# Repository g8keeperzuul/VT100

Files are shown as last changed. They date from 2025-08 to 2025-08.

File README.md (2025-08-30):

# VT100 Serial Terminal

This VT100 serial terminal recreation is approximately 2/3rds [actual size](https://vt100.net/docs/vt100-ug/chapter2.html).
The 3D model was created from scratch in an attempt to be faithful to the style of the original. I also wanted to take advantage of a larger print bed size. It requires a large format print bed (model width is 30cm) to print as is, but can be cut to accommodate smaller print beds. 
The internals accommodate a Raspberry Pi, a small power distribution outlet and a serial port adapter. 

This project was absolutely inspired by the good work of [Michael Gardi](https://hackaday.io/project/177596-23-scale-vt100-terminal-reproduction) and [Lars Brinkhoff](https://github.com/larsbrinkhoff/terminal-simulator). I used the same display hardware, but different serial interface and an upgraded Pi. 

# Enclosure

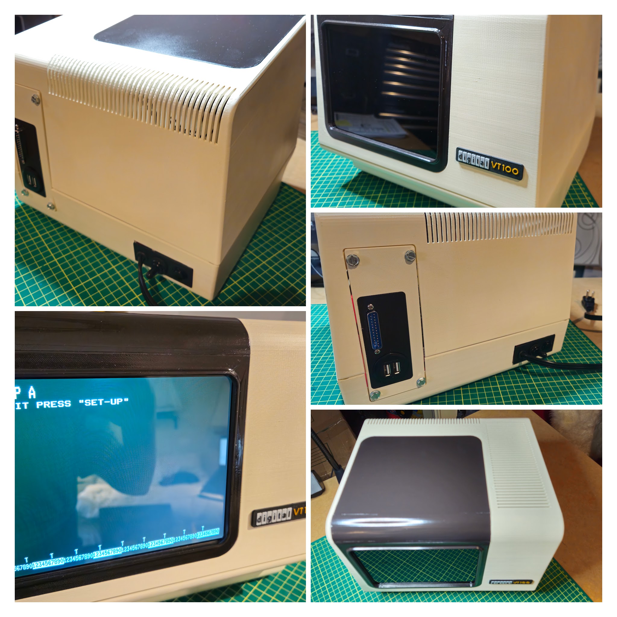
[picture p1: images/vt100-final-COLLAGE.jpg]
collage


## 3D Model
### Main Enclosure: Top and Bottom
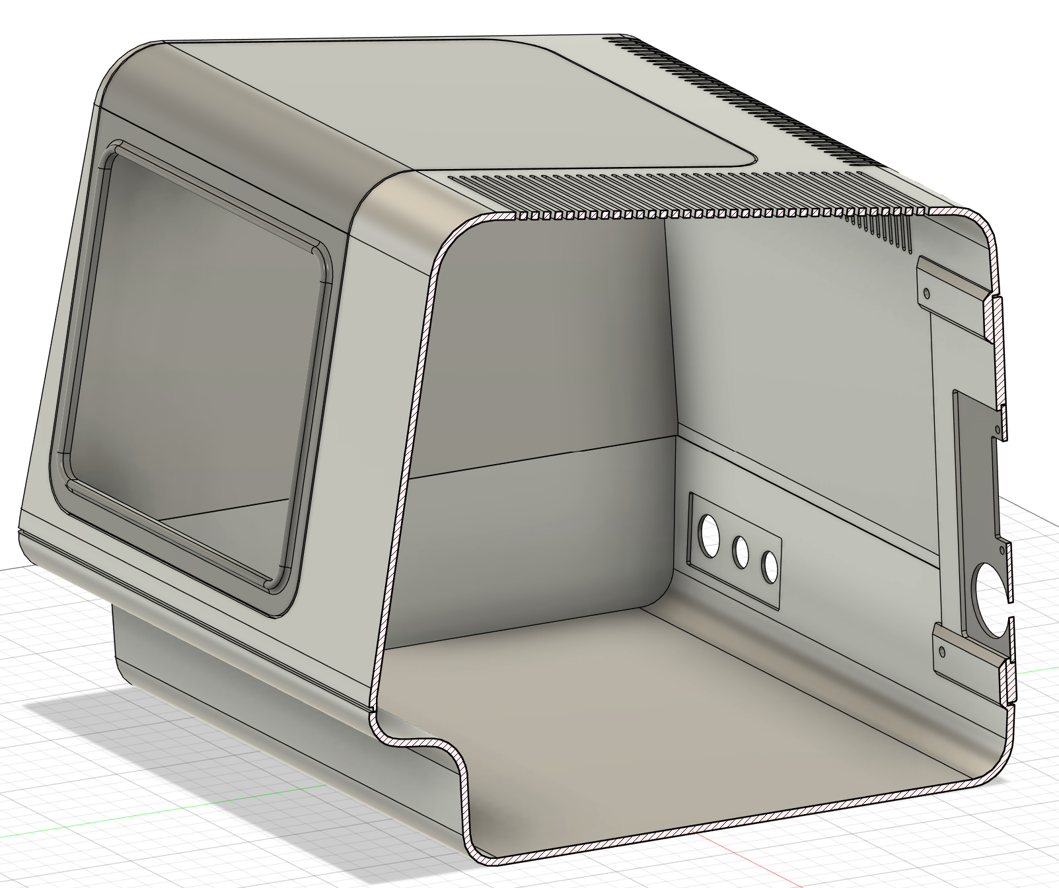
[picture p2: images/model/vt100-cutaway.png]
cutaway

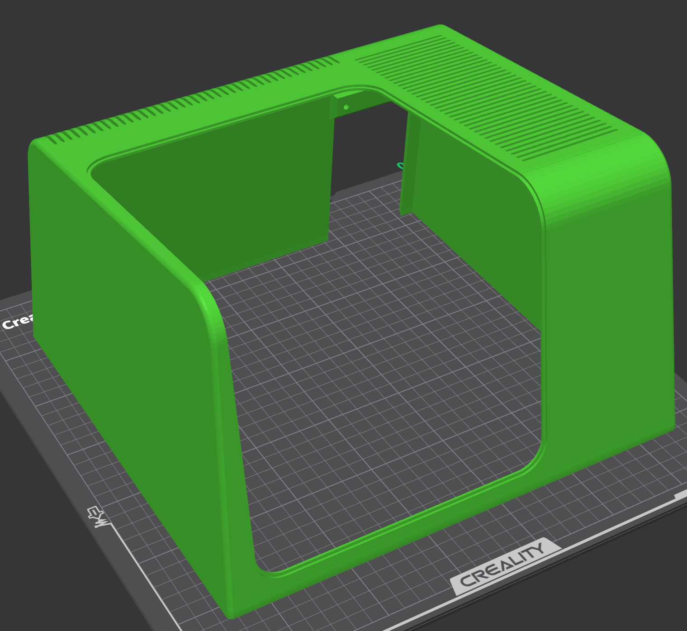
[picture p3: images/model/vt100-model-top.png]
top

Some improvements I would make:

__Top__
* The lip for the bezel is a bit too shallow (2mm if I remember correctly); it should be widened
* Add guide holes/posts or a ridge along the floor where it would attach to the bottom half to make mating the top and bottom pieces easier to align. 

__Bottom__
* I originally added an inset for the LCD control panel under the overhang so that it would be discrete but accessible. It was just a bit too small to fit the control board. I found I really didn't need access to the controls, so I printed up a small panel to plug the hole later. Either remove it completely or enlarge it to accommodate the control board. 
* Add guide holes/posts or a ridge to compliment the same added to the top part.

__Display__
* Have the display slide into the sleeve from below instead of above. This eliminates any need to destroy the top enclosure when removing the display. 

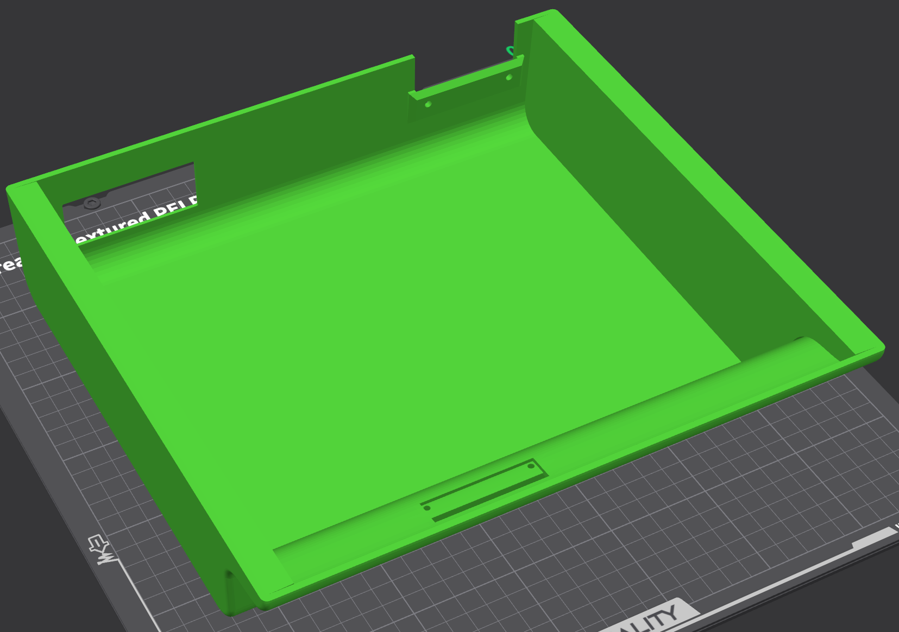
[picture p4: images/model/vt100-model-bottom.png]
bottom


### Attaching Top and Bottom
OK, admittedly this is odd but it works. The bolt is sliced in half and glued *precisely* to the top and bottom halves of the enclosure along the seam (glue while the nut is threaded). When the entire enclosure is sealed up, the back communication panel is screw-fastened, and provides a gap wide enough to get a hand in to thread and un-thread the bolts so that the top can be lifted off. When fastened together, it's strong enough that the entire terminal can be lifted by only the top (not that I would get in the habit of doing this). 
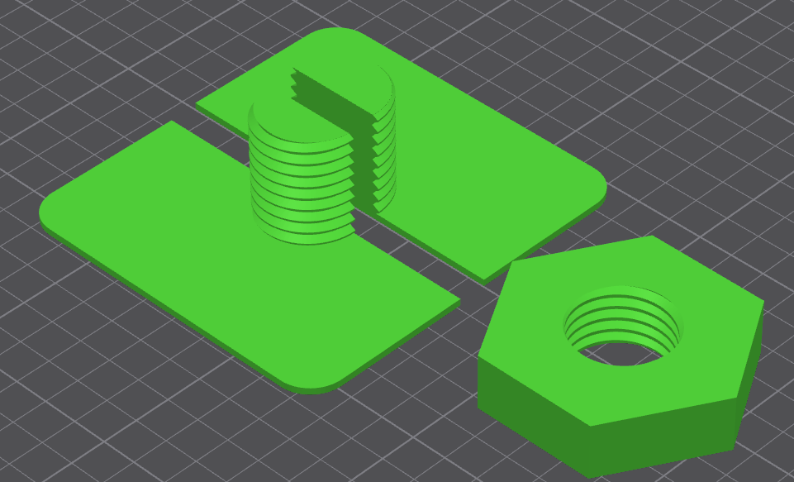
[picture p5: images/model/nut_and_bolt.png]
big nuts


### Main Enclosure: Communication Panel and Power Panel

The inner panel is black and glues into the outer white panel. The entire communication panel is meant to be removable and uses four screws to attach to the bottom and top parts of the enclosure. 

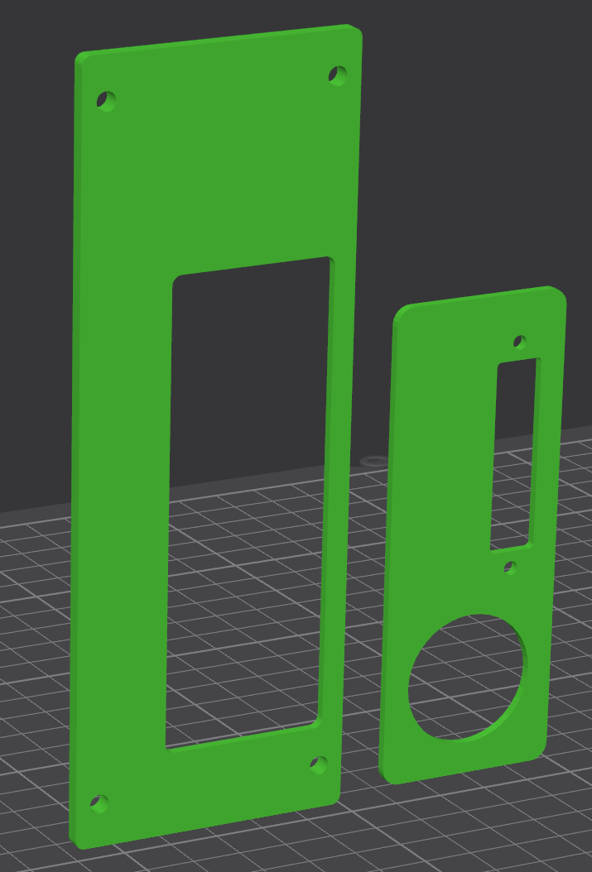
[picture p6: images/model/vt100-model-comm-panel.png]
comm panel


Both the inner communication panel and power panel are designed to allow easy changes without a significant reprint. 

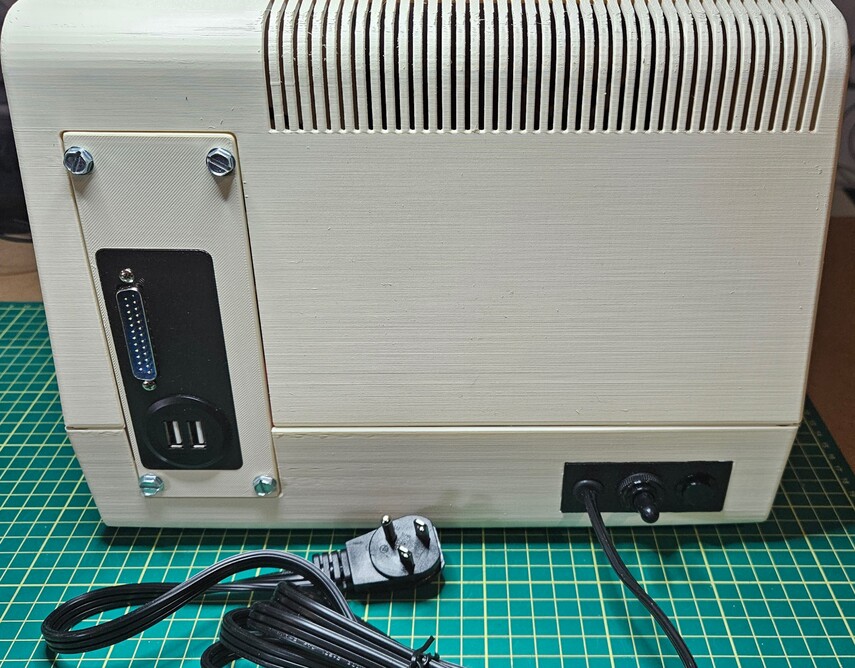
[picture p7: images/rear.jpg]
rear


### Internal Mount: Base

The following internal parts are used to provide attachment points to the mounting board that contains all the electronics. It has hex insets to allow for bolts to be inserted before gluing all three pieces to the inside floor of the bottom half. This will leave the bolts standing up. 

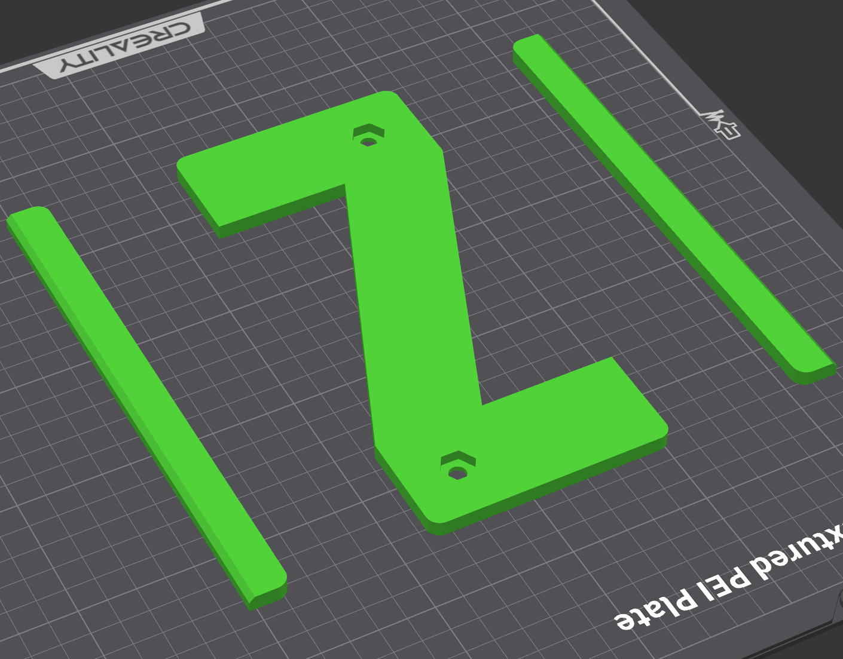
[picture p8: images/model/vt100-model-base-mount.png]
mount


On top of these is a flat mounting board where the Raspberry Pi is installed. While I printed up a board, you can save some filament and simply use thick card stock, cardboard or thin wood. Two holes are needed to allow the bolts to pass through to firmly fix the bounding board tothe bottom half of the enclosure. 
The separate mounting board allows all the electronics and PSU to be worked on without any of the enclosure being needed. Once done, it can easily be dropped in place. 

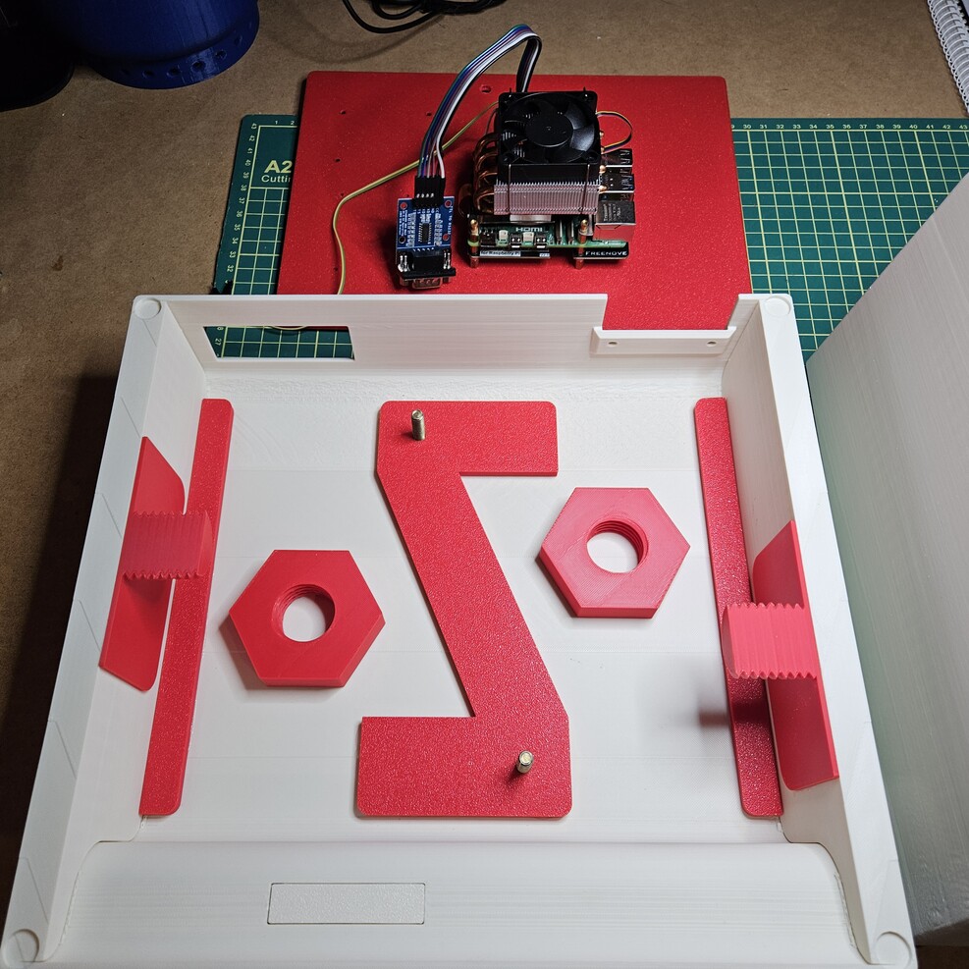
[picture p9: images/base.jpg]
attachment


To attach the top and bottom halves of the enclosure I originally intended on using magnets (you can see the four inset circles at each order - these are not part of the model but just added ad hoc in the slicer). Unfortunately I found they were not strong enough. So I came up with a split bolt and nut. The plastic bolt is split and glued between top and bottom halves and the giant plastic nut keeps the two parts together pretty well, while allowing easy disassembly. The large rear, removable communication panel is used to gain access to manipulate the nuts. 

### Internal Mount: Display

The display driver board has a small controller board. Due to cable length, the driver board is pretty much going to be positioned directly behind the screen. I created a couple of "caddies" that allow the boards to be press-fit without needing any tape or glue. The screen itself slides into a tight-fitting sleeve. The purpose of all this is so that the display and driver board can be popped out an reused. The driver board fit isn't as tight as it should be, and really should be mechanically fastened via the corner holes on the PCB.
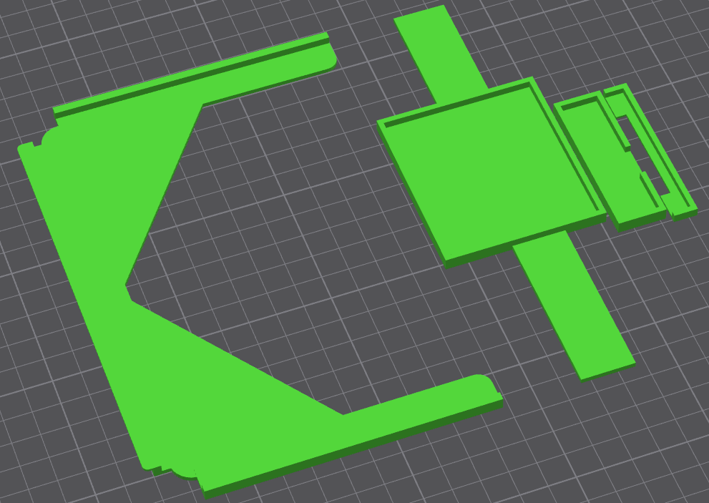
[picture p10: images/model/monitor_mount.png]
lcd mount


Unfortunately, the display needs to slide out in the vertical direction, which is blocked by the curved roof of the enclosure. 
With some better planning on my part, the screen should have slide into the sleeve from below. That way separating the top and bottom enclosures would have provided a means to slide the LCD out. Oh well. 
I encourage you to build a better display and driver board mount.

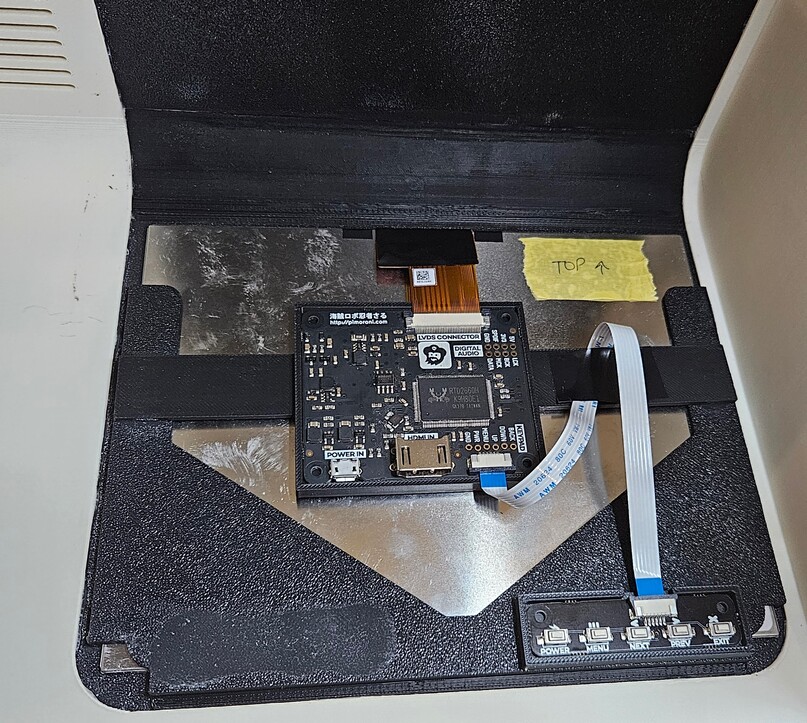
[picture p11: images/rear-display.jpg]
rear display


### Bezel

The bezel is composed of three pieces and are meant to be glued into the top half of the enclosure. The display should be attached before the bezel is glued in place.

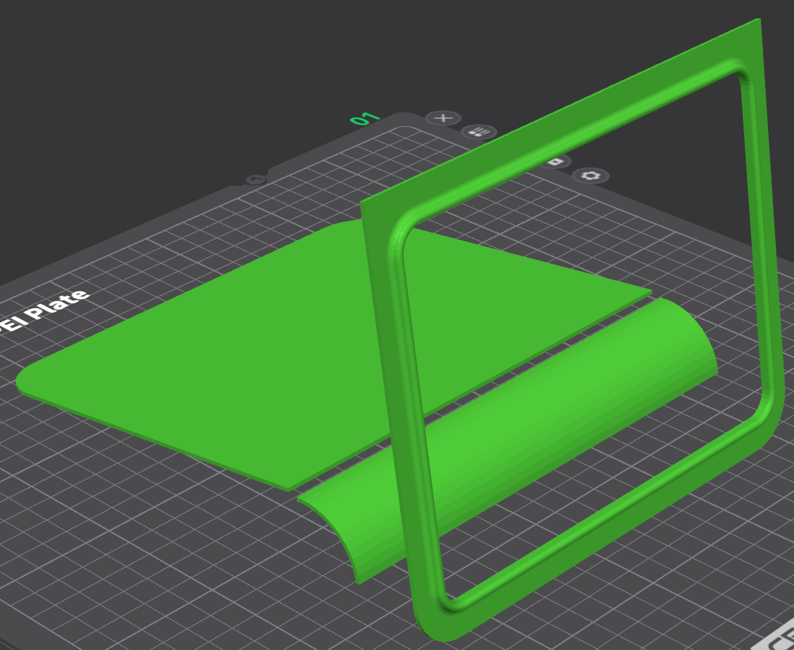
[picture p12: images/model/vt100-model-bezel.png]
bezel


### 3D Model Assets
#### Exterior
| Part | File |
|---|---|
| EVERYTHING | [whole model Fusion360](./3d-models/fusion360/VT100-v42.f3d) |
| Top enclosure | [top stl](./3d-models/VT100-34-top.stl) |
| Top enclosure control panel plug | [control cover stl](./3d-models/VT100-v39-control-cover.stl) | 
| Bottom enclosure | [bottom stl](./3d-models/VT100-v34-bottom.stl) |
| Logo | [digital VT100 stl](./3d-models/Logo.stl), [digital VT100 Fusion360](./3d-models/fusion360/Logo.f3d); Split for multicolor printing: [digital stl](./3d-models/Logo%20digital.stl), [vt100 stl](./3d-models/Logo%20VT100.stl) |
| Power panel | [power panel stl](./3d-models/VT100-target-form-power-panel-v40.stl) |
| Outer communication panel | [comm panel outer stl](./3d-models/VT100-v38-full_comm_panel.stl) |
| Inner communication panel | [comm panel inner stl](./3d-models/VT100-v38-inner_comm_panel.stl) |
| Bezel front | [bezel front stl](./3d-models/VT100-v34-front_monitor_bezel.stl) | 
| Bezel top | [bezel top stl](./3d-models/VT100-v34-top_black_panel_etched.stl) |
| Bezel curved transition | [bezel curved stl](./3d-models/VT100-v34-curved_black_panel.stl) | 

#### Interior
| Part | File |
|---|---|
| Floor mount | [floor mount stl](./3d-models/vt100-mounting_plate_edge%20v6.stl) | 
| Display bracket | [lcd bracket stl](./3d-models/VT100-target-form-bezel-lcd-bracket.stl) |
| Driver PCB mount | [driver pcb mount stl](./3d-models/VT100-target-form-bezel-driver-mount.stl), [driver pcb mount containment bracket stl](./3d-models/VT100-target-form-bezel-containment-bracket.stl) |
| Control PCB mount | [control pcb mount stl](./3d-models/VT100-target-form-bezel-control-board-mount.stl) |
| Giant Bolt & Nut enclosure binder | [bolt top](./3d-models/vt100-case-connector%20top%20v3.stl), [bolt bottom](./3d-models/vt100-case-connector%20bottom%20v3.stl), [nut](./3d-models/vt100-case-connector%20nut%20v3.stl) | 

## Finish and paint

Your 3D prints may have flaws or unsightly artifacts. I used some modelling putty and sandpaper to improve the finish.

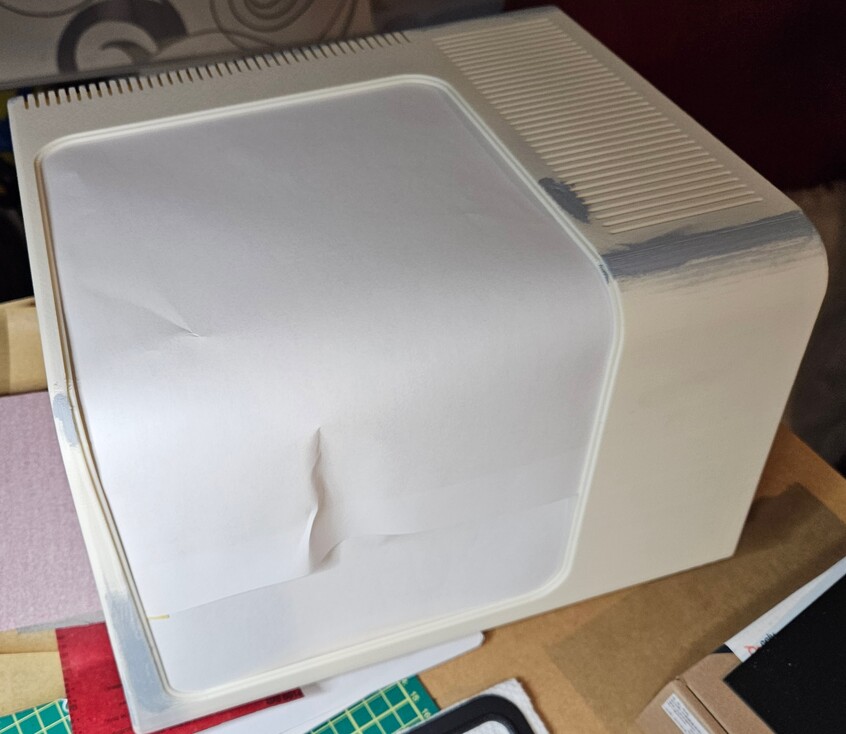
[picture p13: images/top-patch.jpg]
top patched

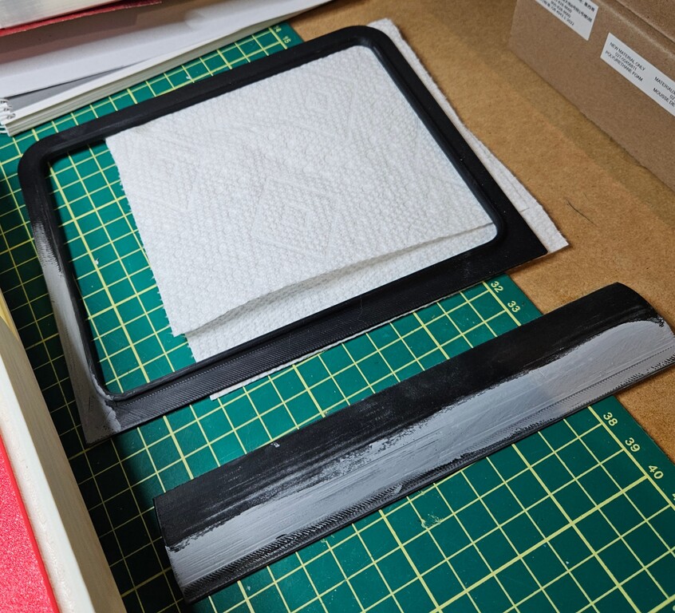
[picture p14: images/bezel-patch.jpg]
bezel patched


I've seen actual VT-100 terminals in a variety of colors depending upon their exposure to UV light and second-hand cigarette smoke. I wanted mine to look vintage but not dirty. I decided upon an off-white and dark brown, almost black. Several coats of paint help fill any imperfections and contributes to a smoother surface. 

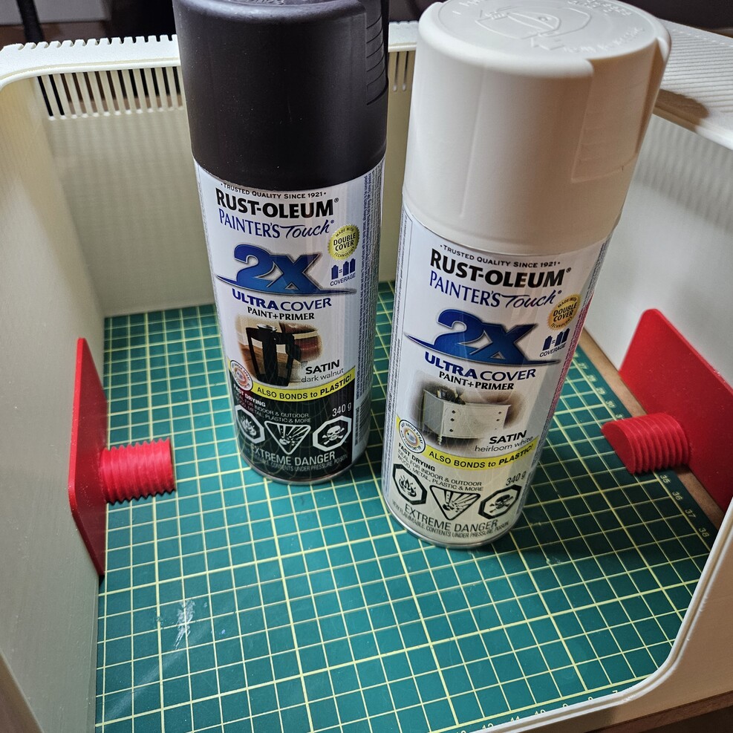
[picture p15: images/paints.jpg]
paints


# Electronics

Fundamentally this is just a Raspberry Pi, a standard HDMI driven display, a serial port, a momentary button and a power switch.

## Communications Panel
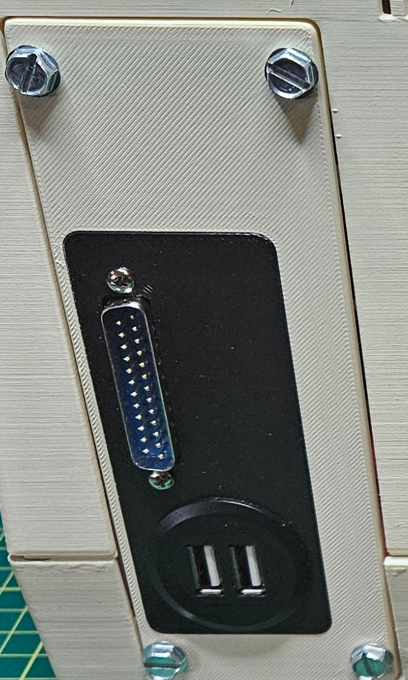
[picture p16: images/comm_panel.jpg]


### Serial port
Raspberry Pis have plenty of serial/uart ports. It is possible to add another serial port via USB, but in this case we will use an existing serial port available via GPIO pins and connect it to a serial TTL level converter.
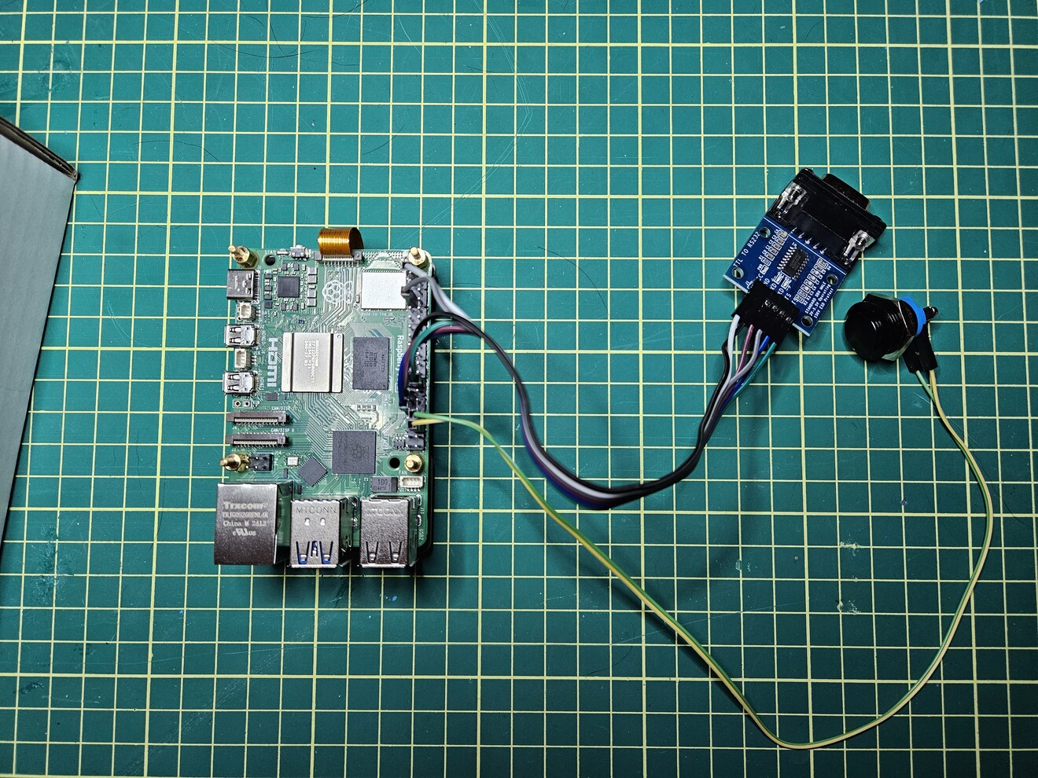
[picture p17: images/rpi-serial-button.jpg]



| Serial | Raspberry Pi GPIO |
| --- | --- |
| TXD | UART 2 transmit - GPIO 5 (29) |
| RXD | UART 2 receive - GPIO 4 (7) |
| CTS | clear to send - GPIO 6 (31) |
| RTS | ready to send - GPIO 7 (26) |
| VCC | 3V3 power (1) |
| GND | Ground (9) | 

This particular serial board includes support for CTS and RTS (not mandatory).
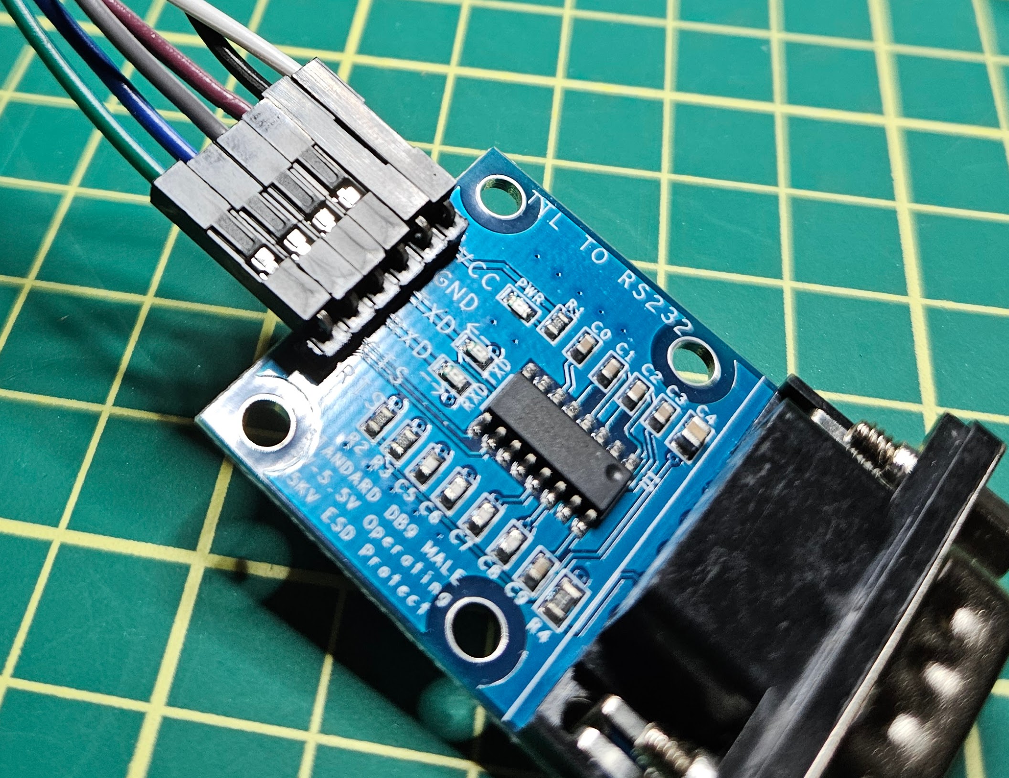
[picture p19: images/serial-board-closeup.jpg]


The DB9 expands into a DB25 for added [authenticity](./images/reference/digital_vt100-back-side.jpg).

[DB25 pinout reference](./doc/Serial_PinoutStndrds.pdf)

To be added to _/boot/firmware/config.txt_:
(Note: this overlay is specific to Raspberry Pi 5, so place it under the correct [section](https://www.raspberrypi.com/documentation/computers/config_txt.html#model-filters))
```
# UART 2
# GPIO 4, 5 : TX, RX
# GPIO 6, 7 : CTS, RTS
dtoverlay=uart2-pi5,ctsrts=on
dtparam=uart2=on
```

If successful, you should see a new physical serial port /dev/ttyAMA2 after reboot. 

Documentated use as per dtoverlay help:
```
$ dtoverlay -h uart2-pi5 

Name:   uart2-pi5 

Info:   Enable uart 2 on GPIOs 4-5. Pi 5 only. 

Usage:  dtoverlay=uart2-pi5,<param> 

Params: ctsrts                  Enable CTS/RTS on GPIOs 6-7 (default off) 
```

### USB ports
These simply extend the USB-A ports from the back of the Pi to the back of the enclosure, via the communications panel. 
Generally they are meant for a keyboard and mouse. 

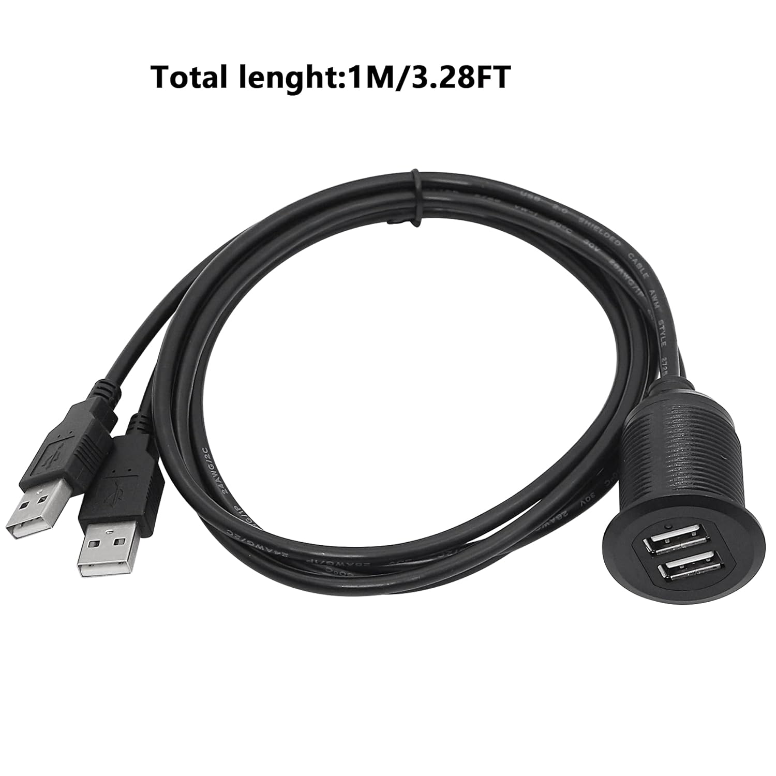
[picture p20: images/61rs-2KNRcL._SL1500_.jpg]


## Power Panel
### Shutdown button
A momentary switch that allows you to initiate a controlled shutdown before shutting off the power.

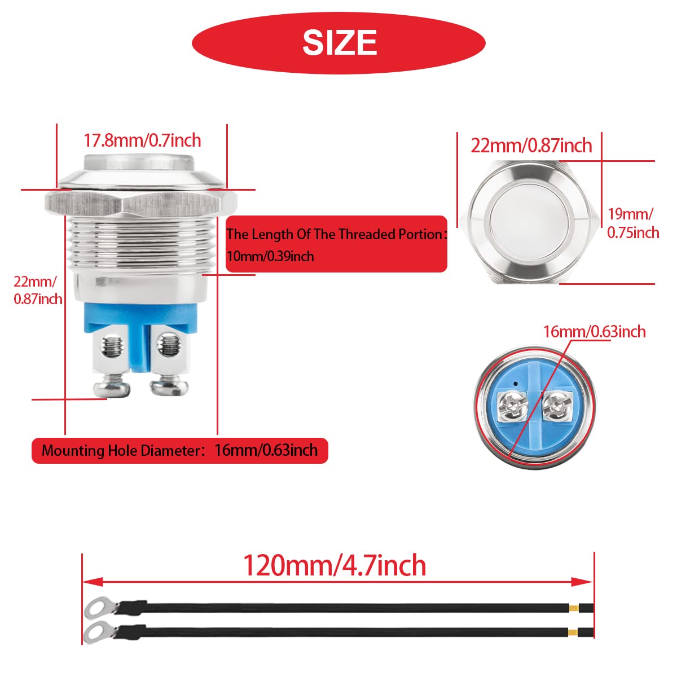
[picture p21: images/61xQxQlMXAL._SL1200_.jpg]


| Button | Raspberry Pi GPIO |
| --- | --- |
| Terminal A | GPIO 16 (36) |
| Terminal B | Ground (34) | 

To be added to the end of _/boot/firmware/config.txt_:
```
# Power off button
# attach to GND + GPIO16
# GPIO is pulled up, pressing the button connects to ground (falling edge=active low)
dtoverlay=gpio-shutdown,gpio_pin=16,gpio_pull=up,active_low=1,debounce=100
```

### Power switch & supply
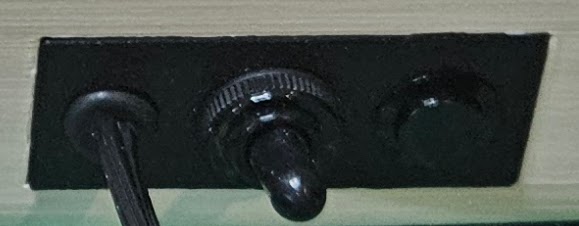
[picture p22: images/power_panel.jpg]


First, it is more authentic to have the AC power cord feed directly into the terminal, rather than having an external power supply. Additionally, the problems with powering both the Raspberry Pi 5 and the LCD display was cumbersome. The RPi5 ideally needed its own proprietary USB-PD power adapter. The LCD was a lot more flexible needing only 5V@1A. 

At first I thought I could simply split the power with an adapter providing 5V via a micro USB-A and 5V via a USB-C, but this didn't work. Because of USB-PD negotiation, the splitter cable needed CC lines supported. However, even then it still didn't work. I abandoned driving everything from the RPi5 PSU. 

I opted to have separate power supplies for the RPi5 and LCD display. To keep things clean and more authentic, I put a really small power bar inside the enclosure. The RPi5 PSU plugs into one of the outlets and a micro USB-A cable connects the power bar to the display driver board. 

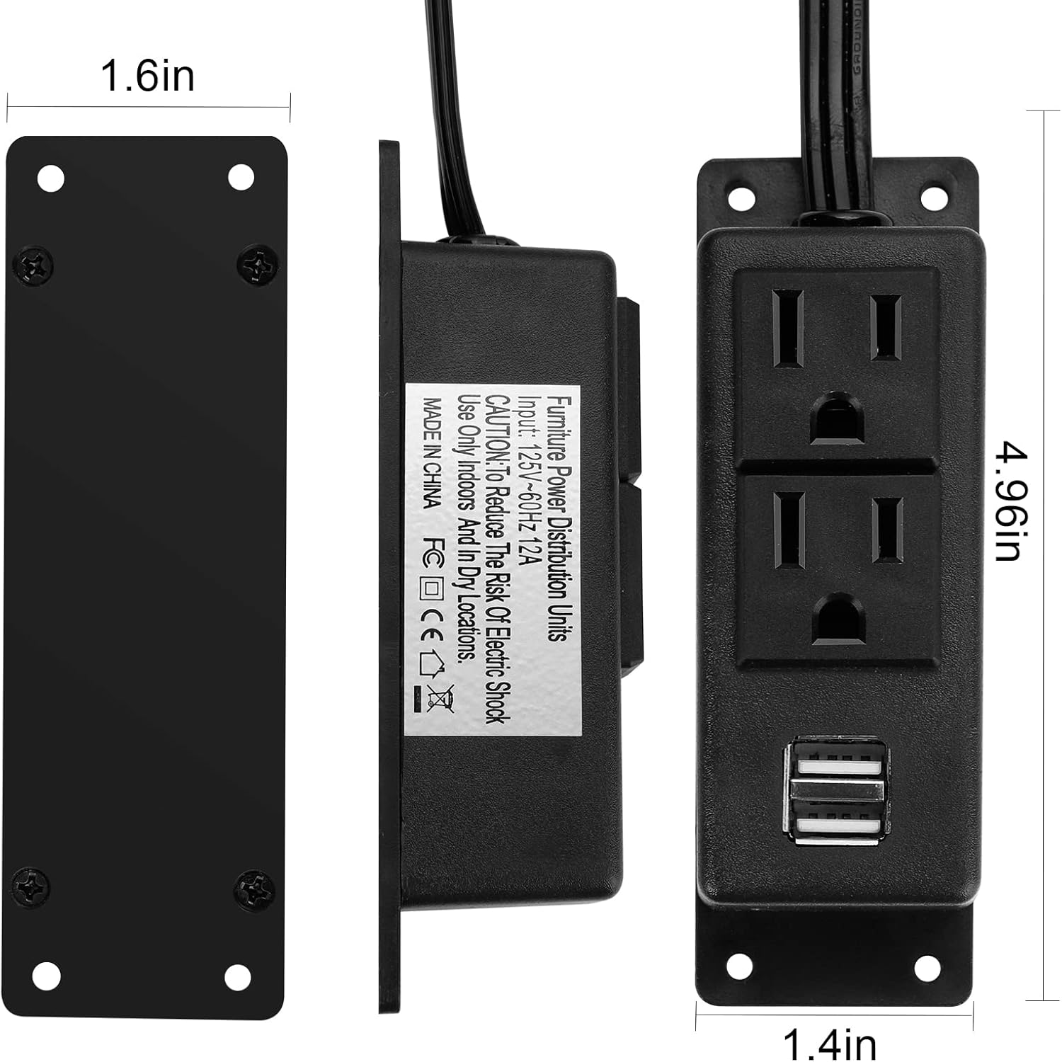
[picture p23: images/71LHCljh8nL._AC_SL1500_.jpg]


An external power switch will be added to this mini power bar. This will allow power to be cut to the Raspberry Pi and display (once a safe shutdown has been done).
A single-pole, single throw (SPST) switch connected to the "hot" (white) wire will suffice. 
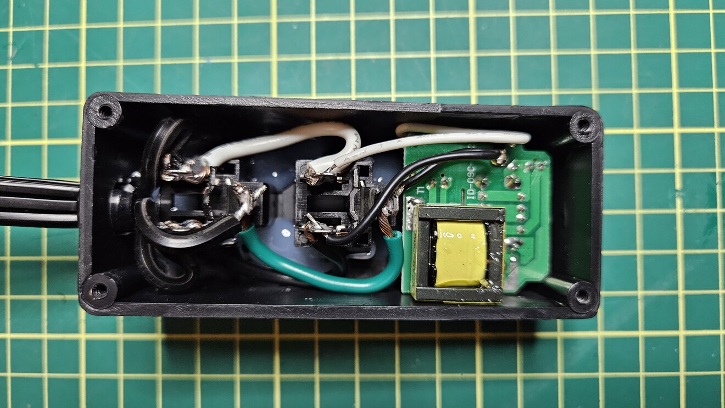
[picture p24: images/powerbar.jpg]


The power cable is desoldered from the outlet and a switch is inserted.

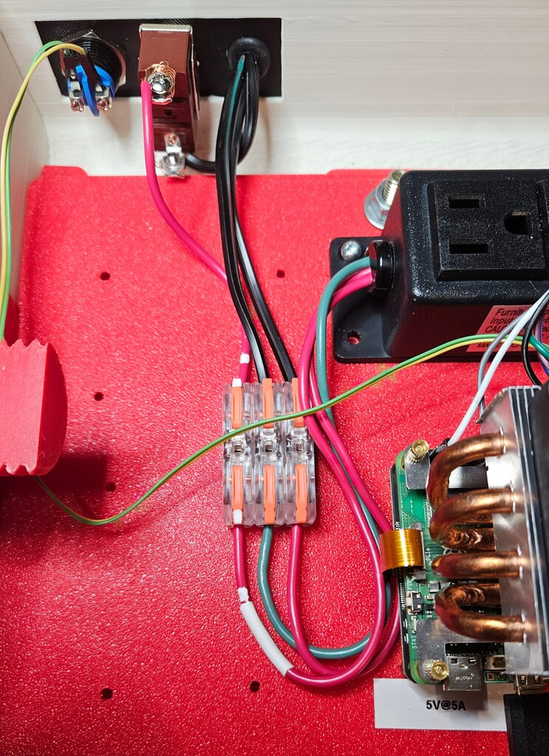
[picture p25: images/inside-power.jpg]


The end result:

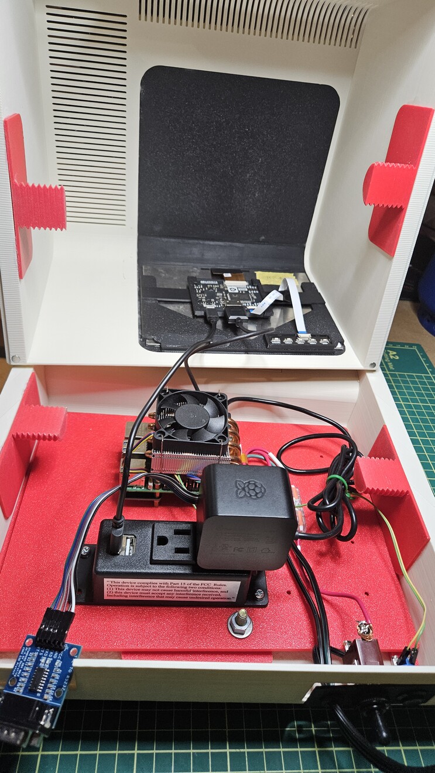
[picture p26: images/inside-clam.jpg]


# Software
## VT100 Emulator

The software emulation of the VT100 basically consists of an 8080 emulator with an image of the actual ROM used by the DEC VT100.
This work is from [Lars Brinkhoff's terminal-simulator project](https://github.com/larsbrinkhoff/terminal-simulator)

To compile the vt100 binary, you will need to have SDL2 and SDL2_image libraries installed (sudo apt install).

```
libsdl2-2.0-0
libsdl2-image-2.0-0
```

```sh
git clone https://github.com/larsbrinkhoff/terminal-simulator.git
cd terminal-simulator
make
```

For command line parameters, see https://github.com/larsbrinkhoff/terminal-simulator/tree/master 
```sh
./vt100 -h
```

Run the terminal full screen (F11 also works):
```sh
./vt100 -f
```

By default the program will display the default (bash) shell. 
Press F9 to get to the "Setup A" screen.
From here, press 5 to get to the "Setup B" screen.
This [manual](https://vt100.net/docs/vt100-ug/chapter1.html) or this [manual](./doc/vt100_tech.pdf) provides the configuration details.

At some point you will want to use it as a real serial terminal.

see https://hackaday.io/project/177596-23-scale-vt100-terminal-reproduction/log/193367-make-the-vt100-reproduction-into-a-true-rs232-terminal

```sh
./vt100 -f /dev/ttyAMA2
```

Unfortunately connecting the vt100 binary directly to the serial port didn't work for me, despite a minicom to minicom interaction working flawlessly from the RPi5 to another host. A quick fix is to simply invoke minicom from within the vt100 shell.

### CRT Effects

This is optional of course, but greatly adds to the realism quotient. It will add a curvature to the corners of the display, as well as make the raster lines much more evident, and give a slight CRT glow to the pixels. Amber, green and white are supported. You will need a more powerful Raspberry Pi for this. Probably a Pi 4 as a minimum. On the Pi 5, the vt100 binary at idle is about 15%. 

```
The command line syntax for vt100 related to visual effects:

-f enters full screen. Toggle with F11.

(white is the default)
-a set pixel color to amber.
-g set pixel color to green.

-c CUR screen curvature (0.0 - 0.5, requires OpenGL)

-2 magnify by 2; each additional -2 adds 1 to multiplier.

-N DIV reduce recomputation of screen to 60/DIV Hz (may run faster).
-Q disables use of OpenGL (may run faster).

```

# Bill of Materials

| Item | Image | Description | 
|---|---|---|
| Raspberry Pi 5 | | A Raspberry 3 or 4 are acceptable substitutes. Compute power is only really needed when rendering the screen as a CRT |
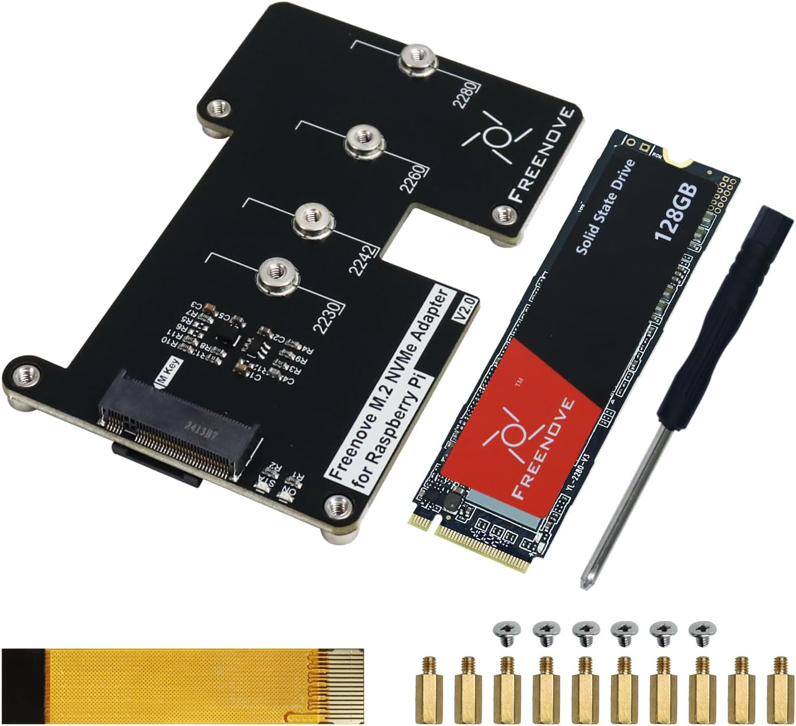
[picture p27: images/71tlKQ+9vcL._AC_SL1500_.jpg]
| PCI to NVMe |  | (Optional) A viable option for a Raspberry Pi 5, otherwise simply use the SDcard | 
| Heatsink | | | 
| USB-A (female) extension |  | To connect USB ports on Raspberry Pi to back of enclosure (via communication panel); used for keyboard (and optional mouse) |
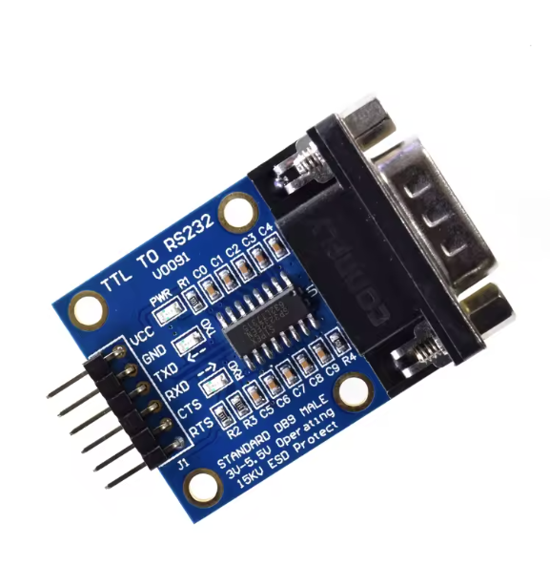
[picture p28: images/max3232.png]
| Serial adapter|  | TTL serial level shifter with CTS and RTS support (not strictly necessary) from [Aliexpress](https://www.aliexpress.com/item/32826758471.html) |
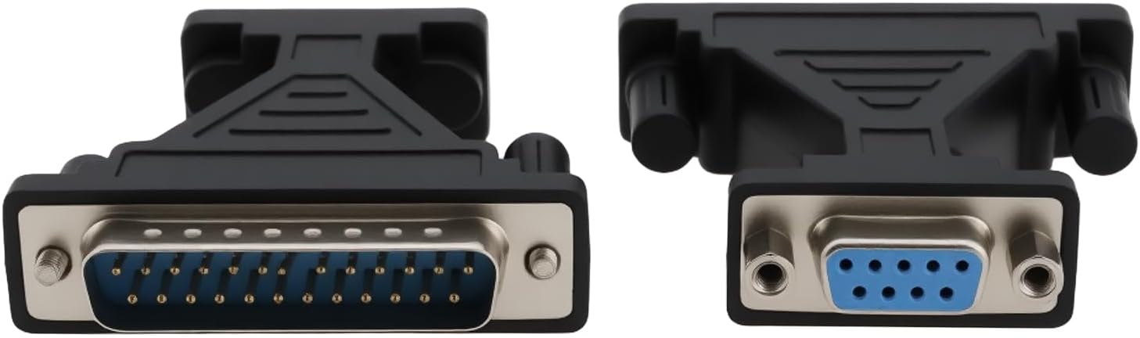
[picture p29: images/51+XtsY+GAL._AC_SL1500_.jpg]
| DB9 to DB25 adapter |  | (Optional) Not strictly necessary, but added for authenticity since the actual VT100s had DB25 serial connectors |
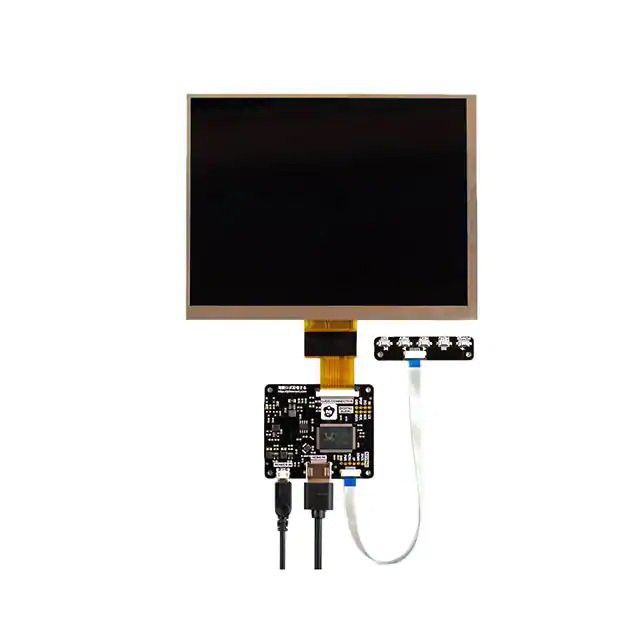
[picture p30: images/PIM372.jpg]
| Display |  | HDMI 8" IPS LCD Screen Kit (1024x768) by Pimoroni [PIM372](https://shop.pimoroni.com/products/hdmi-8-lcd-screen-kit-1024x768?variant=12559868133459) - 4:3 ratio; any 8" 4:3 display with HDMI input should suffice |
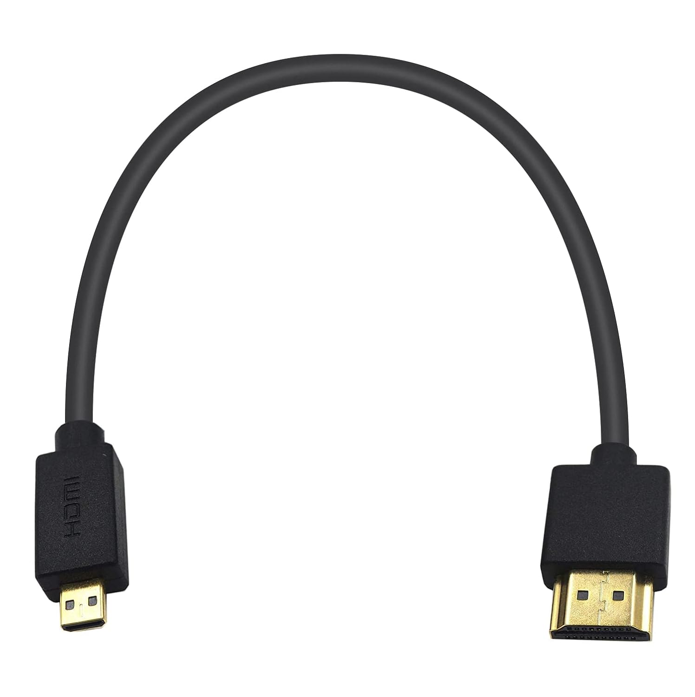
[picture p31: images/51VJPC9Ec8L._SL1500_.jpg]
| Micro HDMI to full HDMI cable |  | About 10cm; micro-HDMI is specific to Raspberry Pi 5 & 4 |
| Momentary switch |  | Used to initiate system shutdown |
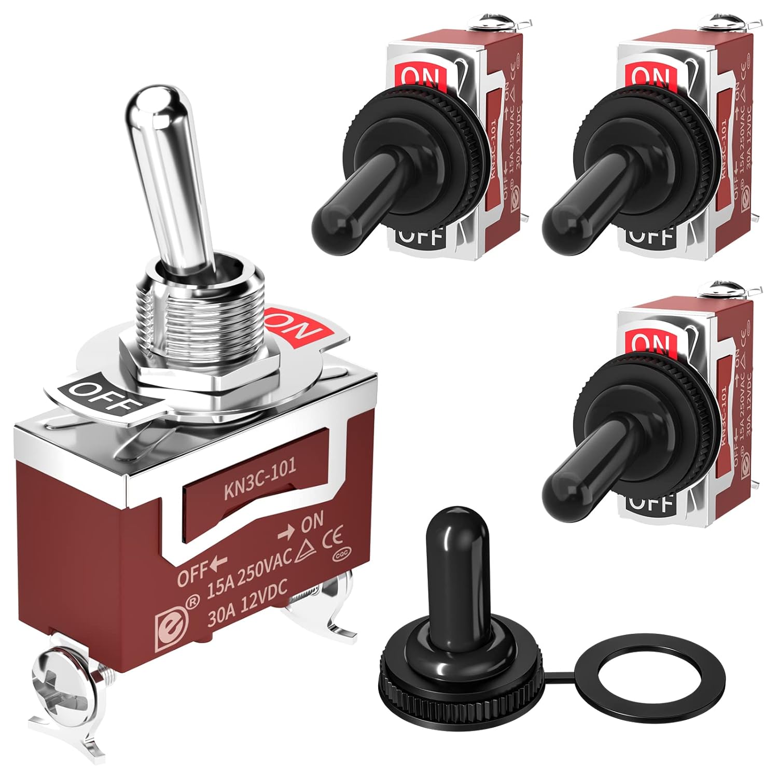
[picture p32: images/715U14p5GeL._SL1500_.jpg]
| SPST switch |  | Used to disconnect main power |
| Power bar |  | Small enough to fit inside the enclosure. [Amazon link](https://www.amazon.ca/dp/B098QT653G) |
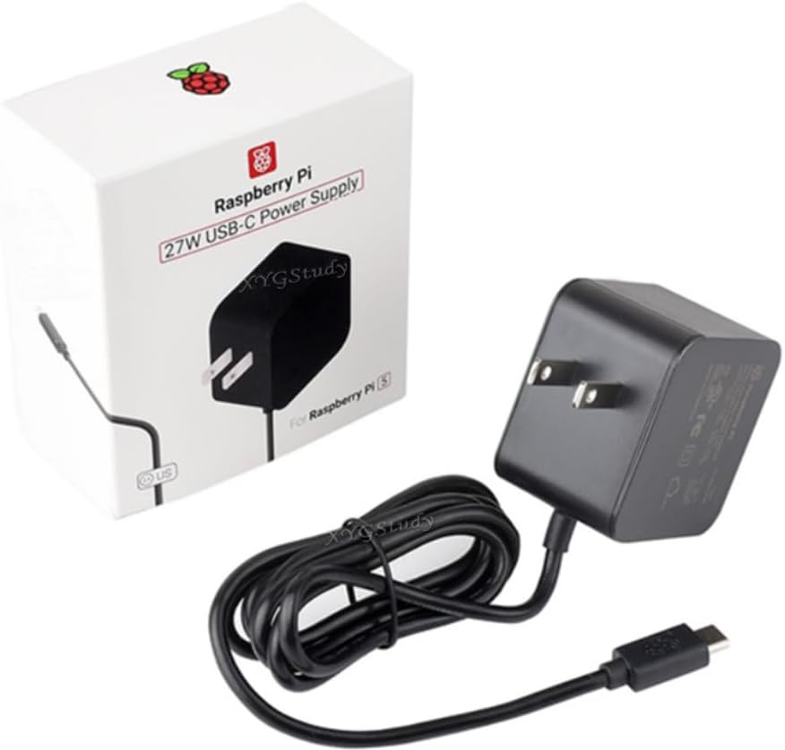
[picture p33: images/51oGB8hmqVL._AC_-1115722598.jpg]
| Raspberry Pi 5 Power supply |  | Not strictly necessary as a PSU with less amps will work (with warnings on a Pi 5); Raspberry Pi 5 PSU delivers USB-PD power of 5V@5A - this is not supported by the USB Power Delivery standard and so requires a special power supply (standard USB-PD delivers 5V@3A) |
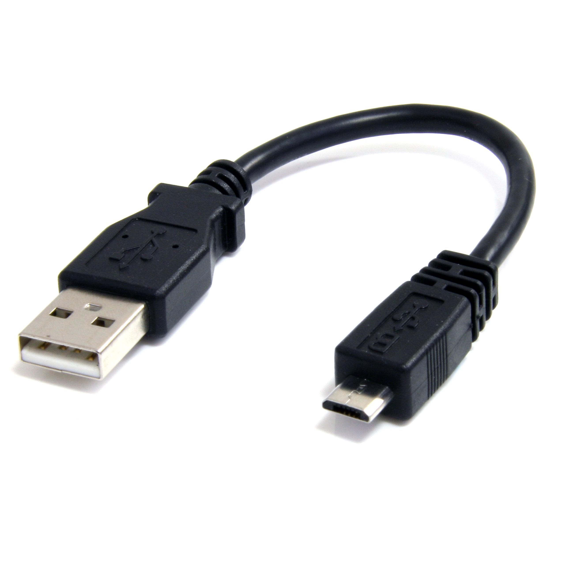
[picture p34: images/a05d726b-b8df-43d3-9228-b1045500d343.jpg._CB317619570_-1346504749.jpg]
| Micro USB-A (male) to USB-A (male) power cable |  | Used to power the display; about 10cm should suffice. Plugs directly into the power bar |
| grommet |  | (Optional) Used to pass the AC power cable out the back of the power panel on the enclosure. Diameter: 3/8", ID: 0.244", OD: 17/32"
| 4 screws (for communication panel), 2 screws (for DB25) |  |  |
| bolt + washer + nut x2 | | Used to secure the mounting board to the bottom-half enclosure |
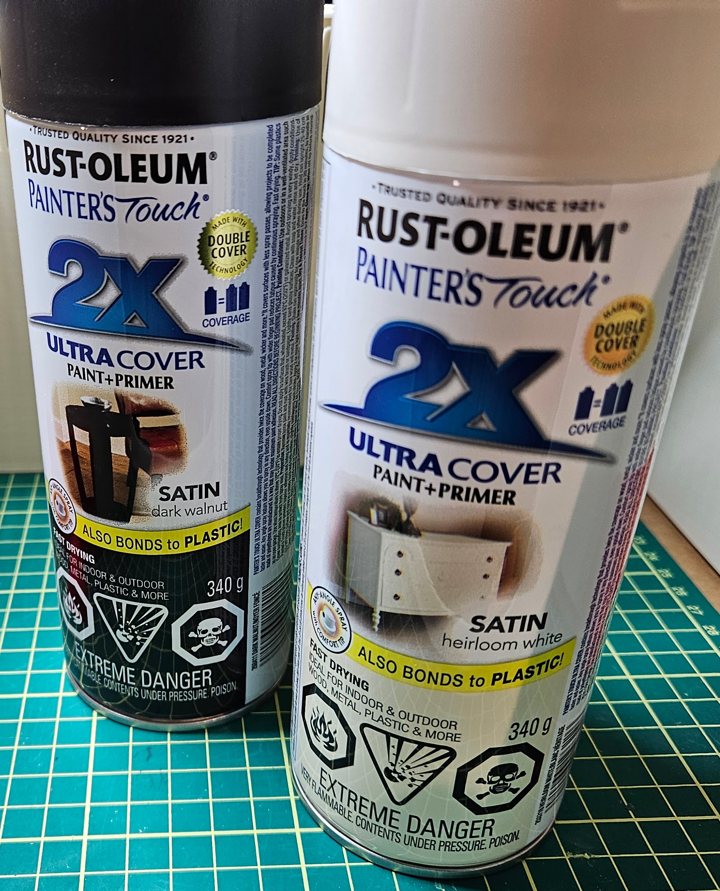
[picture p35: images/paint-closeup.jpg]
| Rustoleum paint<br>Heirloom White<br>Dark Walnut |  | White: Top and bottom enclosure and outer communication panel<br>Black: Bezel, power panel and inner communication panel<br>Paint is optional, but I found  that filler, sandpaper and paint can cover many 3D print imperfections. |

## Future Enhancements

* Add speaker
* Find a thematically suitable keyboard

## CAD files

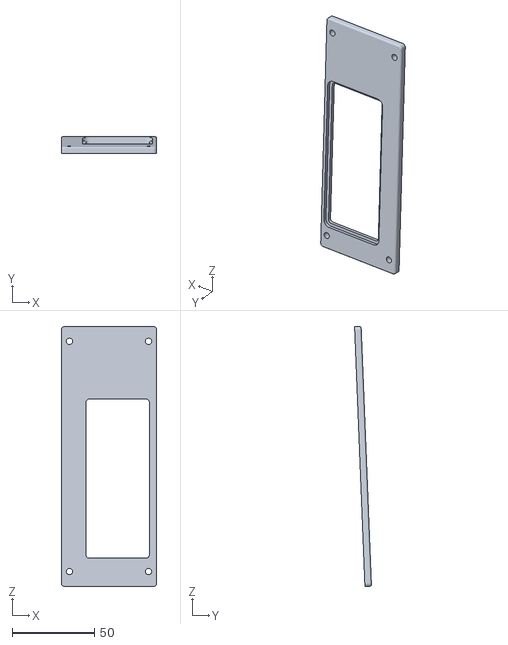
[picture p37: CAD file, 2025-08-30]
3d-models/VT100-v38-full_comm_panel.stl
58.0 x 10.2 x 157.9

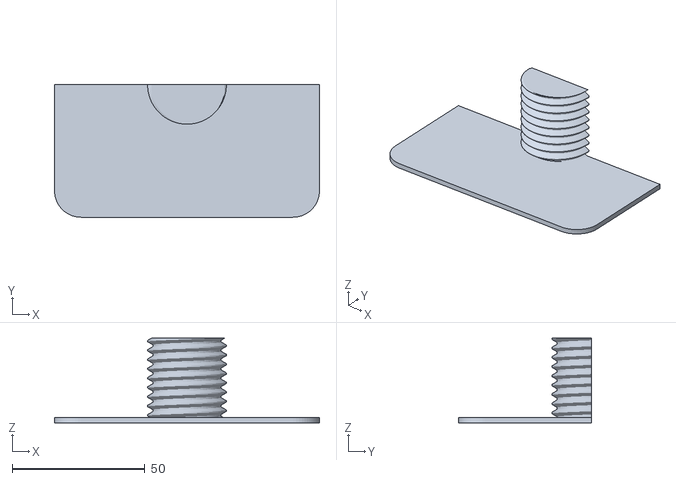
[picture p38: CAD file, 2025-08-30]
3d-models/vt100-case-connector bottom v3.stl
100.0 x 50.0 x 32.0

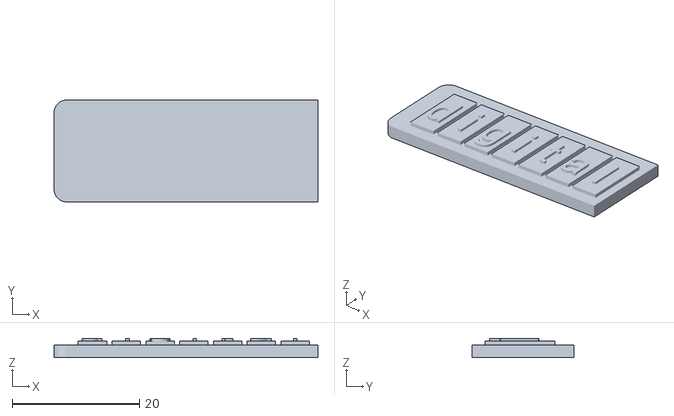
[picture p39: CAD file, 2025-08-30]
3d-models/Logo digital.stl
41.4 x 16.0 x 3.00

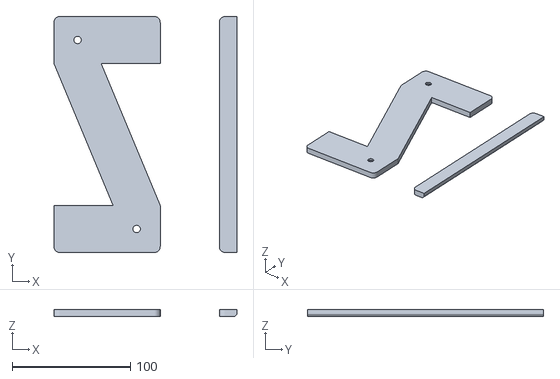
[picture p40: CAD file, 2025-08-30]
3d-models/vt100-mounting_plate_edge v6.stl
155.0 x 200.0 x 6.00

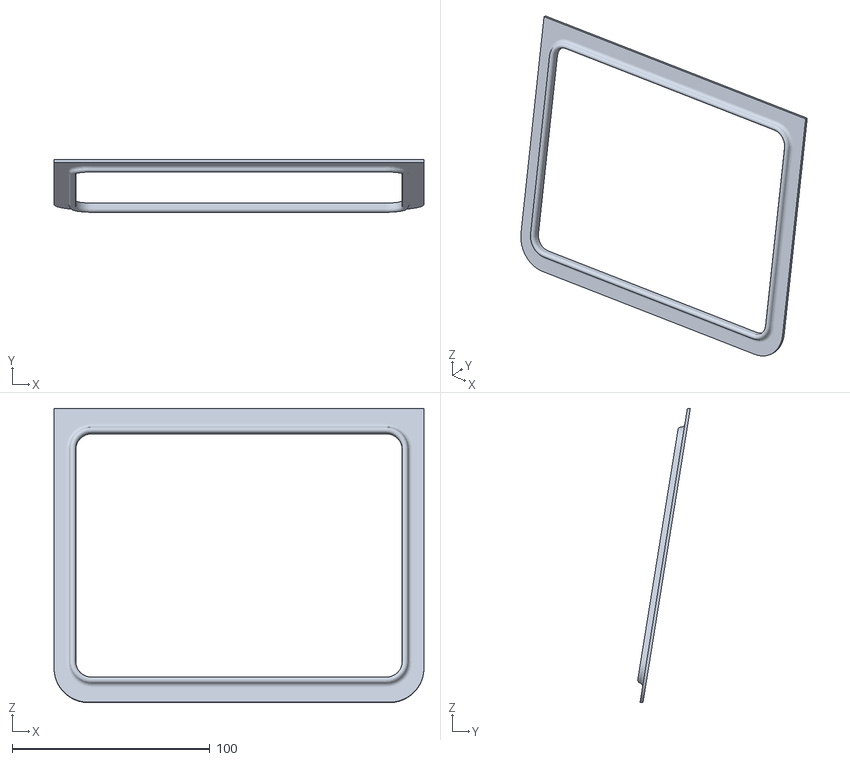
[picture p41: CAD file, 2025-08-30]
3d-models/VT100-v34-front_monitor_bezel.stl
187.0 x 26.6 x 148.8

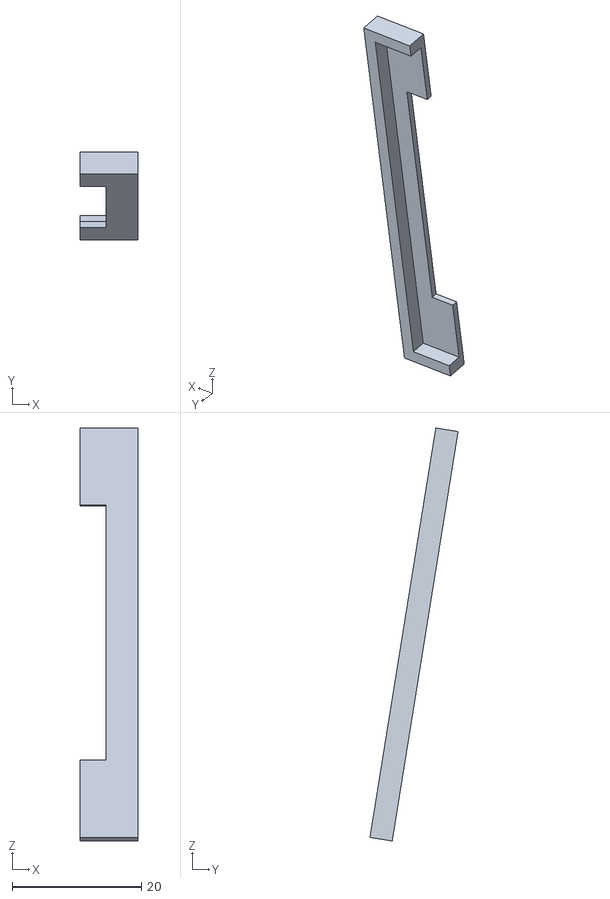
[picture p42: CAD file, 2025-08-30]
3d-models/VT100-target-form-bezel-containment-bracket.stl
9.00 x 13.7 x 63.9

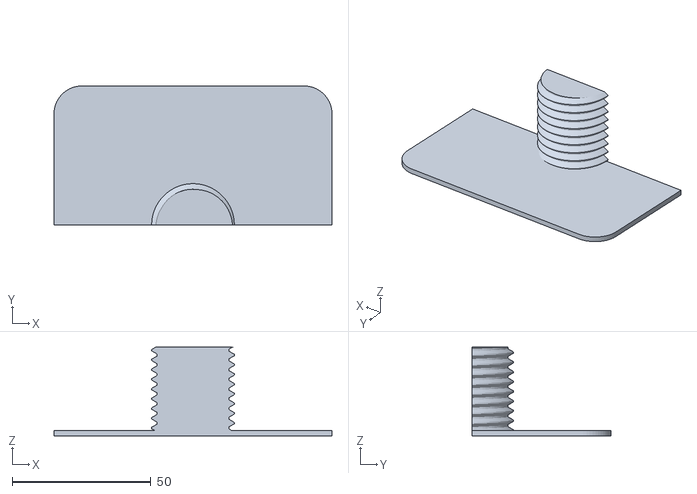
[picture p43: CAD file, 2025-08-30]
3d-models/vt100-case-connector top v3.stl
100.0 x 50.0 x 32.0

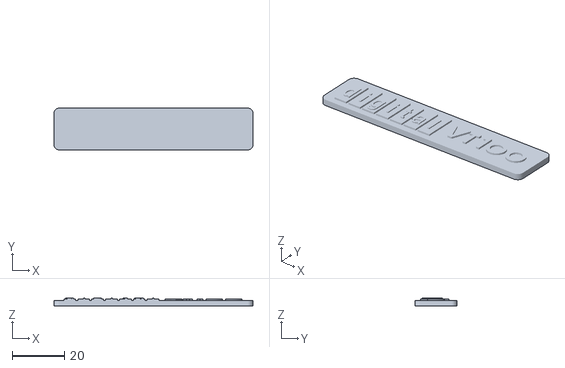
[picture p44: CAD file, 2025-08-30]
3d-models/Logo.stl
76.0 x 16.0 x 3.00

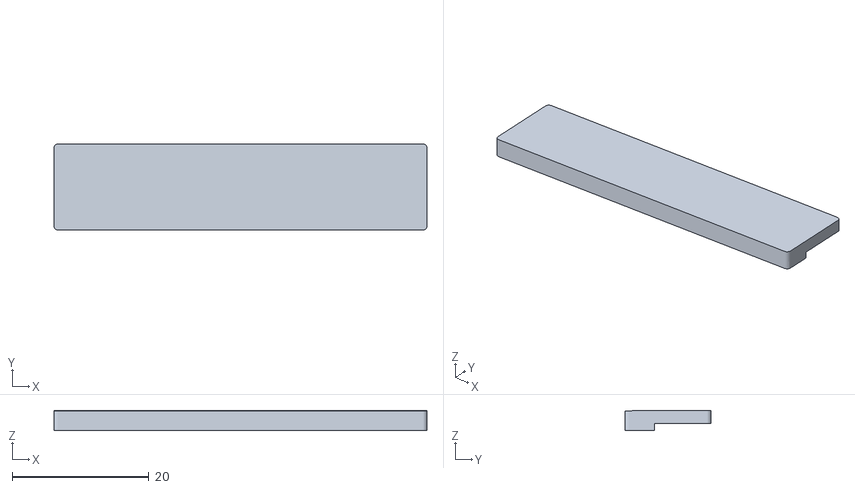
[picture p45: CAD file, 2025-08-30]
3d-models/VT100-v39-control-cover.stl
54.6 x 12.6 x 2.95

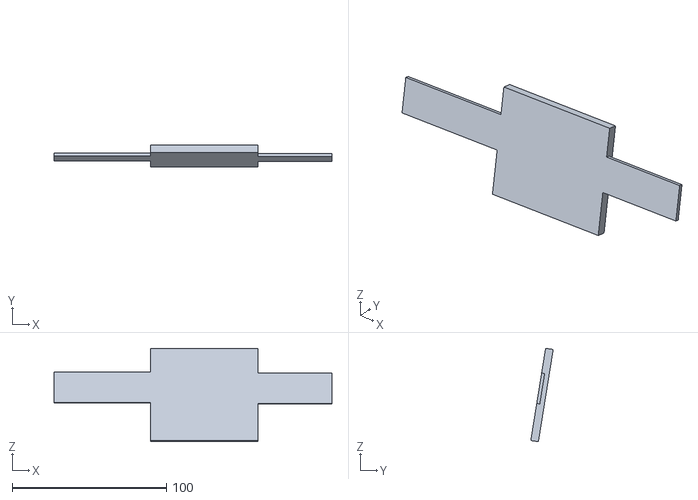
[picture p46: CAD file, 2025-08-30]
3d-models/VT100-target-form-bezel-driver-mount.stl
180.0 x 14.5 x 60.5

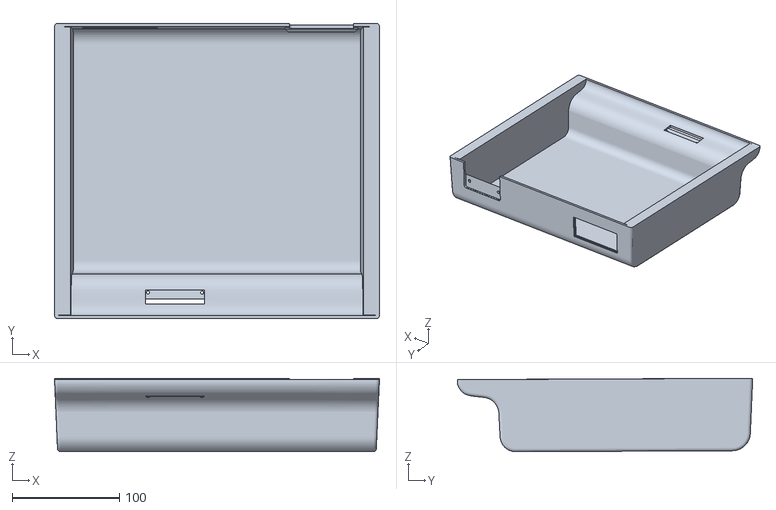
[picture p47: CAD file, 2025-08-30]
3d-models/VT100-v34-bottom.stl
303.0 x 275.4 x 68.4

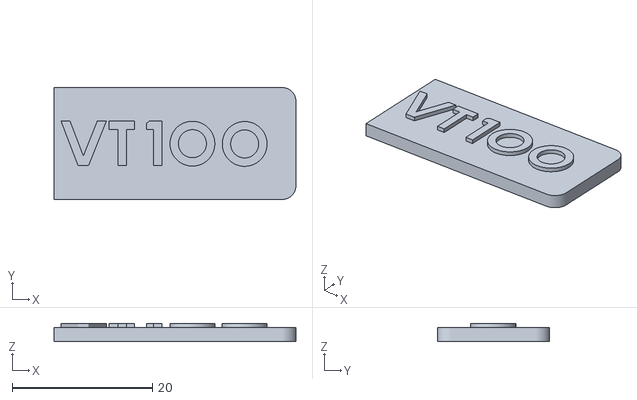
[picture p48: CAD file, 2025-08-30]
3d-models/Logo VT100.stl
34.6 x 16.0 x 2.60

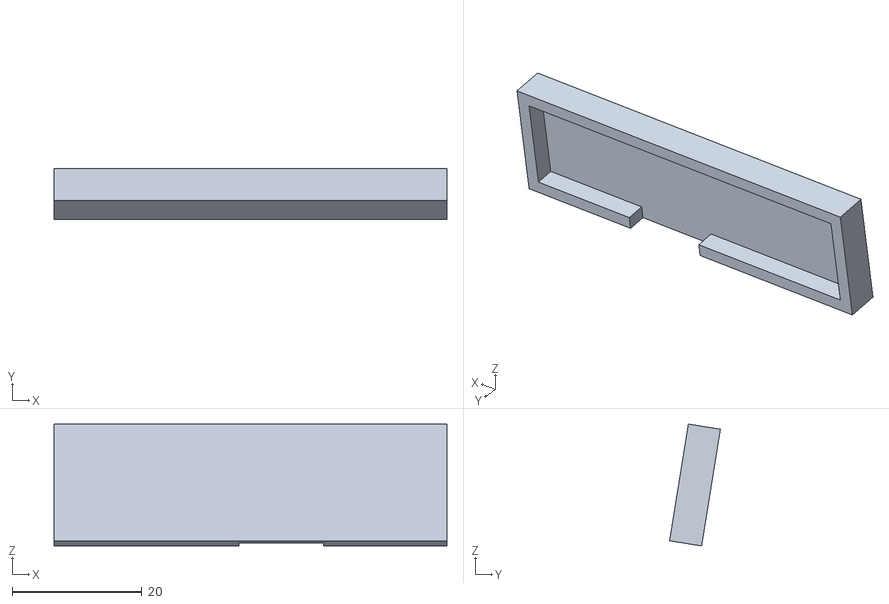
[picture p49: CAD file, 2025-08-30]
3d-models/VT100-target-form-bezel-control-board-mount.stl
60.5 x 7.83 x 18.8

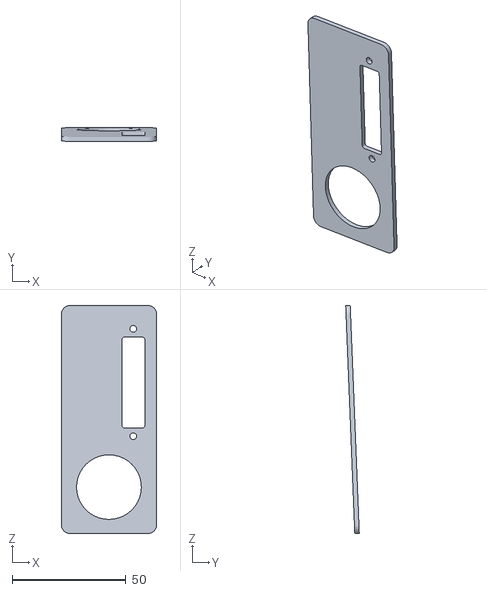
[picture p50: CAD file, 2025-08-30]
3d-models/VT100-v38-inner_comm_panel.stl
41.8 x 5.99 x 100.2

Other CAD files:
3d-models/VT100-target-form-bezel-lcd-bracket.stl
3d-models/VT100-34-top.stl
3d-models/VT100-v34-top_black_panel_etched.stl
3d-models/VT100-v34-curved_black_panel.stl
3d-models/VT100-target-form-power-panel-v40.stl
3d-models/fusion360/Logo.f3d
3d-models/fusion360/VT100-v42.f3d
3d-models/vt100-case-connector nut v3.stl

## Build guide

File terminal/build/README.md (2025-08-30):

# README

The goal of these scripts is to build the vt100 binary from
https://github.com/larsbrinkhoff/terminal-simulator/tree/master

This will not cross-compile to ARM, so you will need to execute all steps on the Raspberry Pi.

There is a 3 stage docker build

1. Recreates the Raspberry Pi OS (based on Debian bookworm) adding in SDL2 (core and image runtimes) in a docker image.

build-rpios-sdl2.sh (uses rpios-sdl2.dockerfile)

2. Using the previously built image, add in development support files and tools for C/C++.

build-rpios-sdl2-dev.sh (uses rpios-sdl2-dev.dockerfile)

3. Using the RPi OS development image, add in the terminal-simulator source and compile terminal-simulator/vt100.

build-vt100.sh <dest-dir> (uses build-vt100.dockerfile)

This shell script will extract three files needed for the VT100 runtime (from the docker image to the host filesystem):
<dest-dir>/vt100
<dest-dir>/common/crt.shader
<dest-dir>/common/vertex.shader

To run on the host (not inside the docker container), you may need to install the SDL2 runtime:

sudo apt install -y libsdl2-2.0-0 libsdl2-image-2.0-0 [...maybe more?]

cd <dest-dir>
./vt100 -h

Question: If NOT running a GUI desktop (just terminal), does the vt100 still work in fullscreen mode (-f) since it uses OpenGL?

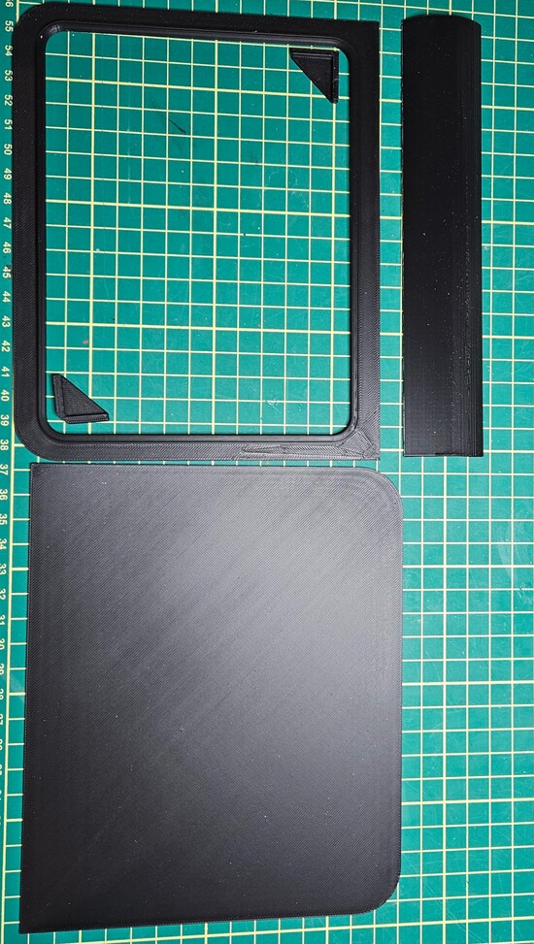
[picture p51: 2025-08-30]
images/bezel-deconstructed.jpg

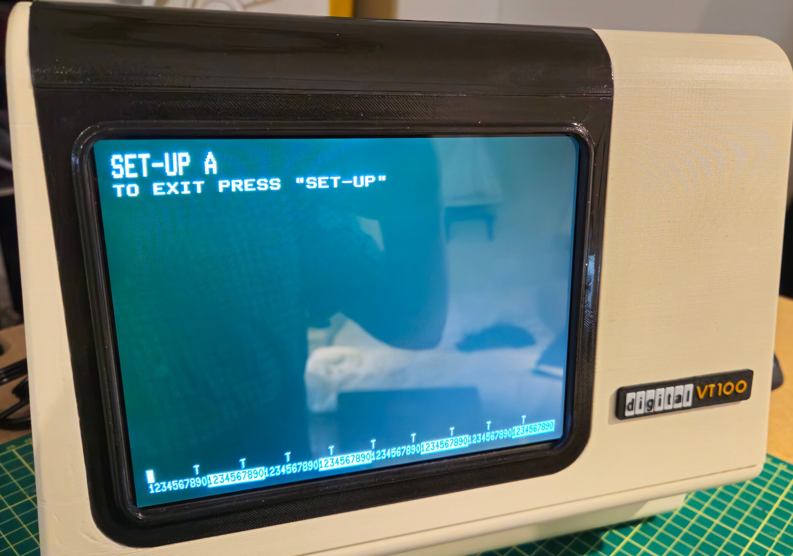
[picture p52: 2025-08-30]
images/vt100-setup.jpg

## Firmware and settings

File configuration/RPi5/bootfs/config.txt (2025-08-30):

# For more options and information see
# http://rptl.io/configtxt
# Some settings may impact device functionality. See link above for details

# Uncomment some or all of these to enable the optional hardware interfaces
#dtparam=i2c_arm=on
#dtparam=i2s=on
#dtparam=spi=on

# Enable audio (loads snd_bcm2835)
dtparam=audio=on

# Additional overlays and parameters are documented
# /boot/firmware/overlays/README

# Automatically load overlays for detected cameras
camera_auto_detect=0

# Automatically load overlays for detected DSI displays
display_auto_detect=1

# Automatically load initramfs files, if found
auto_initramfs=1

# Enable DRM VC4 V3D driver
dtoverlay=vc4-kms-v3d
max_framebuffers=2

# Don't have the firmware create an initial video= setting in cmdline.txt.
# Use the kernel's default instead.
disable_fw_kms_setup=1

# Run in 64-bit mode
arm_64bit=1

# Disable compensation for displays with overscan
disable_overscan=1

# Run as fast as firmware / board allows
arm_boost=1


# enable_uart=1 (in conjunction with console=serial0,115200 in cmdline.txt) requests that the 
# kernel creates a serial console, accessible using GPIOs 14 and 15 (pins 8 and 10 on the 40-pin header). 
# Editing cmdline.txt to remove the line quiet enables boot messages from the kernel to also appear there.
# Setting enable_uart=0 disables ttyAMA0! (not ttyAMA10)
enable_uart=0
# I think this is a special debug UART unique to RPi5 -> /dev/ttyAMA10
# I think this debug UART is not on the GPIO but rather on a dedicated 3 pin header on the RPi5 (between HDMI ports)
# I am not sure if this UART is the same as UART0 accessible on the GPIO header
# this may map to /dev/serial0 if it is the FIRST uart enabled (before dtoverlay=uartX below) NOPE!

# If uart_2ndstage is 1 then enable debug logging to the UART. This option also automatically enables UART logging 
# in start.elf. This is also described on the Boot options page.
# The BOOT_UART property also enables bootloader UART logging but does not enable UART logging in start.elf 
# unless uart_2ndstage=1 is also set.
#uart_2ndstage=0


[cm4]
# Enable host mode on the 2711 built-in XHCI USB controller.
# This line should be removed if the legacy DWC2 controller is required
# (e.g. for USB device mode) or if USB support is not required.
otg_mode=1

#[cm5]
[pi5]
dtoverlay=dwc2,dr_mode=host

# Enable PCIe
dtparam=pciex1
#dtparam=pciex1_gen=2

# DEBUG UART
# /dev/ttyAMA10
# so far always enabled (maybe only disabled when UART0 is used as debug uart)

# UART 0 
# GPIO 14,15 (TX,RX) by default, but can be changed via overlay param
# /dev/ttyAMA0 (or ttyAMA10 if enable_uart=0 !)
# the first serial port will be aliased to /dev/serial0 (it may be the debug port if enabled /dev/ttyAMA10)
# commenting this out, or setting uart0=off does NOT disable uart0 (ttyAMA0 is always created)
# only enable_uart=0 disables ttyAMA0
#dtoverlay=uart0
#dtparam=uart0=on
# make it the debug uart (instead of the dedicated debug uart connector between the HDMI ports)
# set BOOT_UART=1 in EEPROM/flash
# set uart_2ndstage=1 in config.txt
# even with all this configured, you can only ever get EEPROM output from the dedicated 3-pin JST debug uart
#dtparam=uart0_console

# UART 1
# GPIO 0,1
#dtoverlay=uart1-pi5
#dtparam=uart1=on

# Bluetooth
# has a dedicated UART on RPi5
# does not seem to disable any UARTs (such as ttyS0)
#dtoverlay=disable-bt
# also disable systemd service 'hciuart'

# UART 2 
# GPIO 4,5
dtoverlay=uart2-pi5
dtparam=uart2=on

# UART 3
# GPIO 8,9
dtoverlay=uart3-pi5
dtparam=uart3=on

# UART 4
# GPIO 12,13


# When set to 1, firmware initialises RP1 UART0 to 115200bps and doesn’t reset RP1 before starting the OS 
# (separately configurable using pciex4_reset=1). This makes it easier to get UART output on the 40-pin header 
# in early boot-code, for instance during bare-metal debug.
#enable_rp1_uart=0x0

# By default, the PCIe x4 controller used by RP1 is reset before starting the operating system. If this parameter 
# is set to 0 then the reset is disabled allowing operating system or bare metal code to inherit the PCIe 
# configuration setup from the bootloader.
#pciex4_reset=1

[all]

# Necessary if you have a power supply that can supply 5A, but it is not USB-PD capable (so the RPi cannot query it)
usb_max_current_enable=1

# Power off button
# attach to GND + GPIO16
# GPIO is pulled up, pressing the button connects to ground (falling edge=active low)
dtoverlay=gpio-shutdown,gpio_pin=16,gpio_pull=up,active_low=1,debounce=100
